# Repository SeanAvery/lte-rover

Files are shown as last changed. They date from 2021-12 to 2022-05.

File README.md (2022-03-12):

The goal is to control rc car remotely over lte network and stream video back in real time.

Its like a videogame but irl.

Imagine shredding new york city streets in a 1/8 scale that goes 40+ mph. doordash people stop buying electric bikes do the deliveries w small rover.

### Overview

Camera is a comma.ai style andrioid phone with front/back image sensor. The MCU is a simple arduino nano that controls brushelss motor via BLX100 ESC and a steering servo.

### controls flow

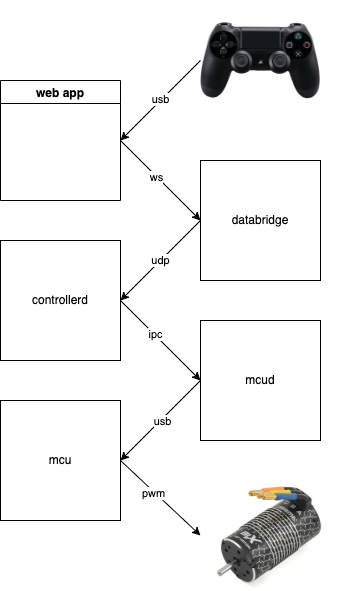
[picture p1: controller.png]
controls flow


### video flow

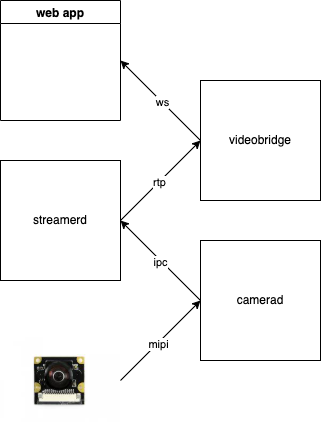
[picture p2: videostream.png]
videostream


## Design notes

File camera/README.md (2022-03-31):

# camera

This is basically turning into a mini-openpilot taking qualcomm camera code, usb communication stuff, and video encoding module out. Just need to add video streaming code (rtp or ideally webrtc/janus).

## Processes

### mcud

1. Libusb driver for mcu (ftdi)
2. Subscriber to `controls` events over zmq
3. Writes `controls` packets over usb
4. Reads `mcu_state` packets over usb

```
make build-mcud
./mcu

```

### controllerd
1. Daemon udp server receives packets from data-bridge
2. Publishes `controls` packets over zmq

```
make build-controllerd
./controller
```

### camerad

```
may just run straight op for this one

./camerad # from openpilot build
```

### streamerd
1. Accepts frame packets over VisionIPC
2. Encodes to h64 using OpenMax
3. Streams over RTP to video-bridge

```
make build-streamerd
./streamer
```

## Communication

### Wireless

Linux socket. Udp on wifi for now. 

Todo: tcp over lte

### Interprocess

checkout out openpilot's cereal library

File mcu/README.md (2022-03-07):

# mcu

Steering and throttle control from arduino.

The goal of this microntroller is to keep things simple - just receive serial commands, perform safety checks, and execute controls.

### hardware

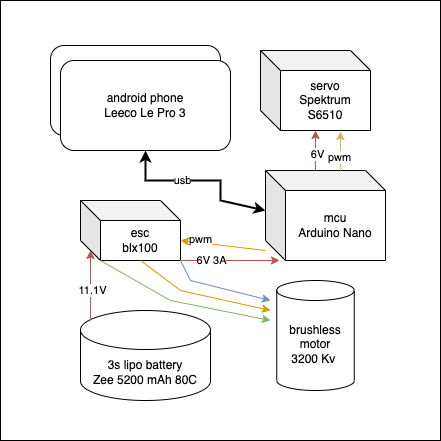
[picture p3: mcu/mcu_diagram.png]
mcu diagram


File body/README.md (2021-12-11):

All parts will be 3d printable (targeting ABS prints).

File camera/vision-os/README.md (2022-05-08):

Snapdragon 821 Vision Stack WIP

# why

openpilot codebase is good reference material but not well suited as robotics framework

plus 821 support has ended and the comma C3 dev board/cameras are way too expensive if you want to develop your own product

lets split software up into composable tools, and make a cheap/usable qualcomm dev board

# hardware setup

Leeco Le Pro 3 running NEOS

# mvp software

1. camera capture
2. encoder
3. rtp streamer

# reach goals

1. cython bindings
2. replacable camera/lens (imx 219 fisheye)

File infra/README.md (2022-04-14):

# infra

this is the cloud bridge for webrtc video streaming and controls

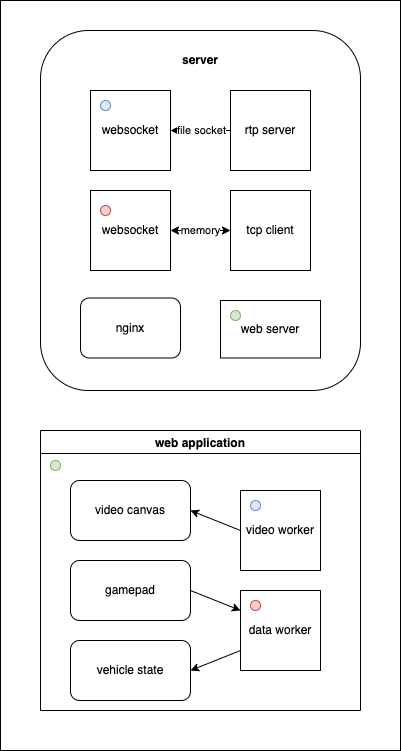
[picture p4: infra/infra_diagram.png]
infra architecture


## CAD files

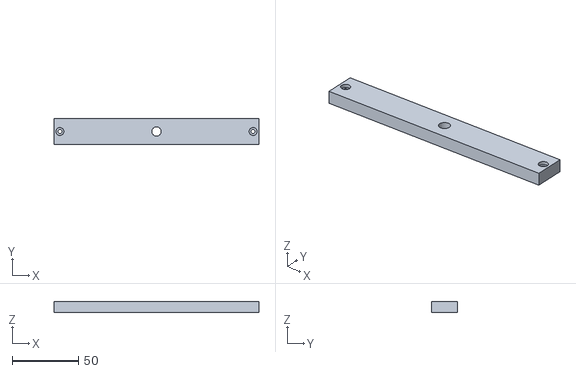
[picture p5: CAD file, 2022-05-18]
body/crossbeam.stl
155.0 x 20.0 x 8.00

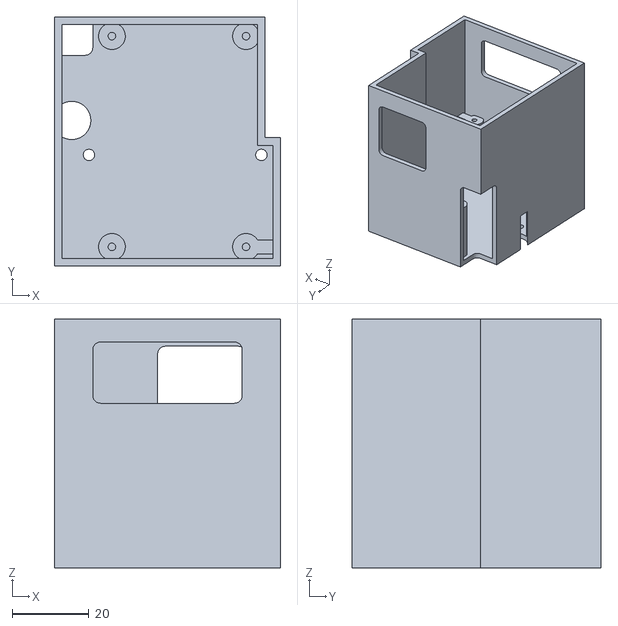
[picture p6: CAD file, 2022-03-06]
body/mcu_enclosure.stl
59.0 x 65.0 x 65.0

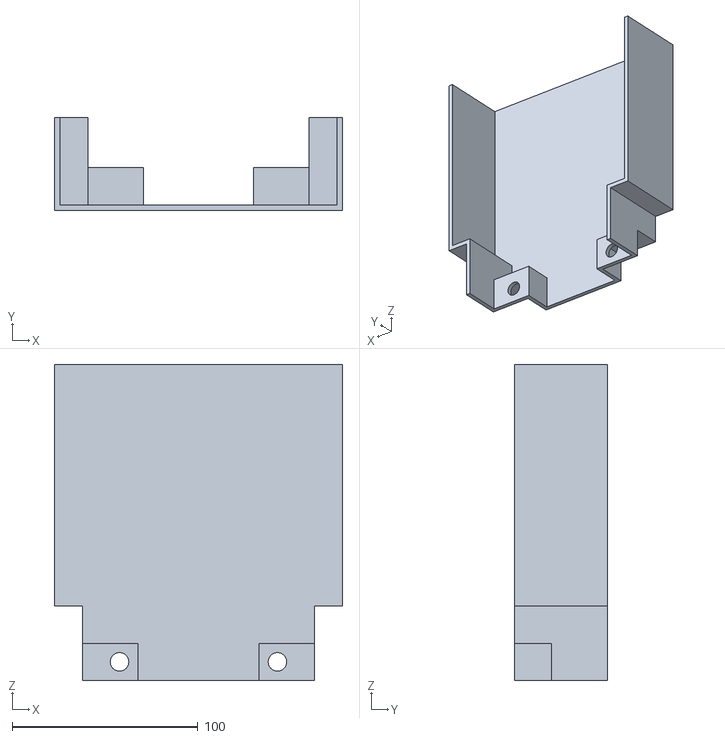
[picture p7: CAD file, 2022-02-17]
body/hood.stl
155.0 x 50.0 x 170.0

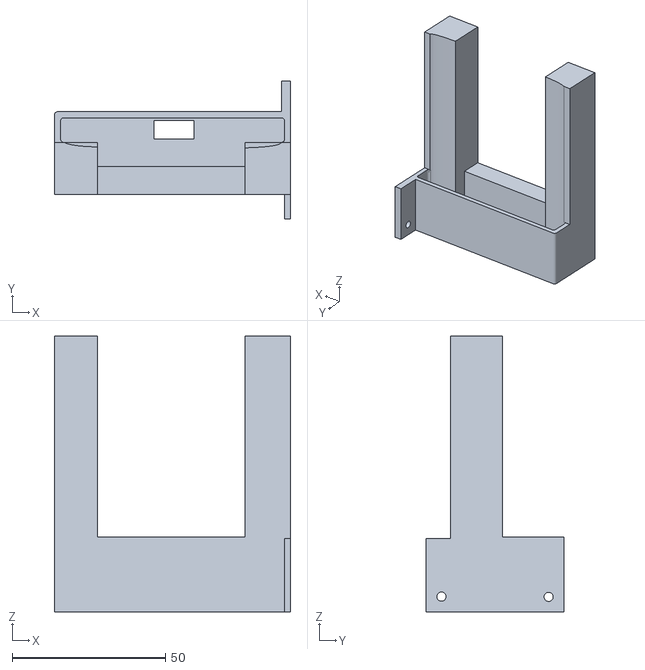
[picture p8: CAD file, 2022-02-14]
body/camera_mount_left.stl
77.0 x 45.0 x 90.0

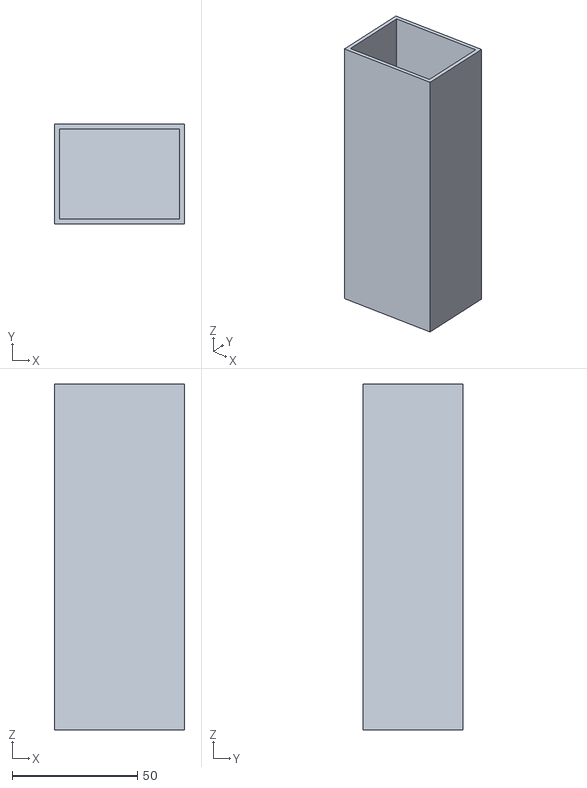
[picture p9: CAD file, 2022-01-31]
body/battery_case.stl
52.0 x 40.0 x 138.0

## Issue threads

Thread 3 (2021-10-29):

rear camera bringup

SeanAvery, 2021-10-29:
### Resources:

[v4l2 subdevices](https://01.org/linuxgraphics/gfx-docs/drm/media/kapi/v4l2-subdev.html)

[qualcomm camera subsystems](https://www.kernel.org/doc/html/v4.14/media/v4l-drivers/qcom_camss.html)

SeanAvery, 2021-10-30:
### Goal:

Need to reverse engineer the rear camera api on my one plus 3 device.

Hopefully, I can just copy the old openpilot camera code

SeanAvery, 2021-10-30:
### Qualcomm camera systems

`csiphy`: handles camera input

`csid`:

`ispif`:

`vfe`:

SeanAvery, 2021-11-10:
https://medium.com/@athul929/capture-an-image-using-v4l2-api-5b6022d79e1d

SeanAvery, 2021-11-18:
# csid cfg error

___

- [ ] try to match clang sdk version
- [ ] use clang that comes with openpilot
- [ ] check import structure
- [ ] debug the ioctl call

SeanAvery, 2021-11-19:
# camera specs (OV8865)

https://android.googlesource.com/kernel/msm.git/+/android-msm-bullhead-3.10-n-preview-1/drivers/media/platform/msm/camera_v2/Kconfig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

SeanAvery, 2021-11-19:
# [qualcomm msm kernel headers](https://android.googlesource.com/platform/hardware/qcom/msm8960/+/e1c9fe3f8195d664a60a04083c3f5de2402b8dee/original-kernel-headers/media)

SeanAvery, 2021-11-21:
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

SeanAvery, 2021-11-21:
###  [ov8865 driver](https://android.googlesource.com/kernel/msm/+/android-msm-shamu-3.10-m-preview/drivers/media/platform/msm/camera_v2/sensor/ov8865.c)

SeanAvery, 2021-11-22:
### [enable kernel debugging](https://elinux.org/Jetson/l4t/Camera_BringUp)

SeanAvery, 2021-11-22:
### [v4l2 events][(](https://www.kernel.org/doc/html/v4.9/media/kapi/v4l2-event.html))

Closed 2021-11-22.

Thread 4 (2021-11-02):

libusb communication bridge between camera and mcu

SeanAvery, 2021-11-02:
[libusb documentaion](https://libusb.sourceforge.io/api-1.0/)

SeanAvery, 2021-12-13:
- [x] get libusb linked to executable
- [x] find usb device
- [ ] up usb device
- [ ] send message
- [ ] receive message

SeanAvery, 2021-12-15:
[openpilot panda.cc](https://github.com/commaai/openpilot/blob/master/selfdrive/boardd/panda.cc)

SeanAvery, 2021-12-15:
[sync libusb tutorial](https://www.dreamincode.net/forums/topic/148707-introduction-to-using-libusb-10/)

SeanAvery, 2021-12-15:
[pigeon.cc]((https://github.com/commaai/openpilot/blob/master/selfdrive/boardd/pigeon.cc)

SeanAvery, 2022-01-20:
### usb ERRNOT
[stack overflow post](https://stackoverflow.com/questions/44122912/libusb-error-submit-bulk-transfer-submiturb-failed-error-1-errno-2-what-am)

SeanAvery, 2022-03-07:
- [ ] format message # protocol
- [ ] async write
- [ ] async read

SeanAvery, 2022-03-08:
### [libusb async tutorial](https://libusb.sourceforge.io/api-1.0/libusb_io.html)

Closed 2022-03-10.

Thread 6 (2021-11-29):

leeco le pro 3 camera specs

SeanAvery, 2021-11-29:

SeanAvery, 2021-12-01:
### [leeco specs](https://www.gsmarena.com/leeco_le_pro3-8344.php)

SeanAvery, 2022-04-22:
### rear camera

Sony IMX298 image sensor with autofocus lens
```
16 MP
f 2.0
```

### front camera

OV8865 sensor (autofocus ???)

```
8 MP
```

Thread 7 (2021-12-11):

arrma car harness

SeanAvery, 2021-12-11:
Control esc, steering servo, and motor fan from arduino

SeanAvery, 2021-12-11:
### debug esc pwm

SeanAvery, 2021-12-11:
### blx 100 esc
[
](https://www.arrma-rc.com/power-systems/latest/blx100)

SeanAvery, 2021-12-13:
should i add head/break lights : 0

SeanAvery, 2022-01-18:
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

SeanAvery, 2022-03-03:
use pins 5 and 6 on arduino nano for 980 Hz pwm

SeanAvery, 2022-03-05:
### problem: pwm dropoff when using usb interface

try things:

- [ ] cut power trace in usb cable from camera to mcu

SeanAvery, 2022-03-05:
### steering

[Spektrum S6510](https://www.hobbytown.com/spektrum-rc-s651-7kg-metal-gear-waterproof-servo-spms651/p1252957)

SeanAvery, 2022-03-06:
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

SeanAvery, 2022-03-07:
mcu 0.1 finished

Closed 2022-03-07.

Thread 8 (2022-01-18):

smart battery

SeanAvery, 2022-01-18:

SeanAvery, 2022-03-18:
[video tutorial](https://www.youtube.com/watch?v=gCS-p8VnSlg)

SeanAvery, 2022-03-26:
- [x] measure cells with multimeter

```
on full charge
cell 1:  10.41
cell 2: 6.23
cell 3: 3.12
```

SeanAvery, 2022-03-26:
- [ ] get current measurements
- [ ] calculate resistor scaling needed for arduino pins

AlexandreSato, 2022-04-13:
if u use same resistors so adc pin aways vin/2

SeanAvery, 2022-04-13:
@AlexandreSato Thanks for comment.

Yes tested using equal value resistors to drop voltage in half. Cell 3 is 11+V so need to drop more than that. Trying to figure out if I need separate arduino for battery or if I can fit it all in the mcu. If separated would need to communicate through usb hub and eon to the mcu or directly through the rx/tx lines.

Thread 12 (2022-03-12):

mcud: usb up issue

SeanAvery, 2022-03-12:
- [x] check if kernel is attached
- [x] check interface claim

SeanAvery, 2022-03-26:
works when i connect with python serial library then run custom libusb.

may be do to baudrate issue (check this later)

SeanAvery, 2022-03-29:
### [ftdi usb driver](https://github.com/wjakob/libftdi)

SeanAvery, 2022-03-31:
## libftdi
### pros:
Clean comprehensive library. Easy to build on device wtith clang and neos libusb pkg.

### cons:
Does not specifically support `FT232RL`. Reset and setting baudrate failing out of the box.

SeanAvery, 2022-03-31:
[FT232RL api docs](http://ibm-1401.info/FeretichEmulator/FT232_FT245_APIv131.pdf)

SeanAvery, 2022-03-31:
i got scammed! arduino nano knockoff does not actually ship with ftdi chip. it comes with `CH340`
https://cdn.sparkfun.com/datasheets/Dev/Arduino/Other/CH340DS1.PDF

SeanAvery, 2022-03-31:
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

SeanAvery, 2022-03-31:
## CH340G Driver

[nice libusb gist ](https://gist.github.com/z4yx/8d9ecad151dad351fbbb)

SeanAvery, 2022-04-01:
[Si lbas documentation](https://www.silabs.com/documents/public/application-notes/AN571.pdf)

SeanAvery, 2022-04-01:
### COM Driver Option

One option is to use the `CH341SER` driver to get COM port. And then just use serial library in python from there.

SeanAvery, 2022-04-01:
# wireshark usb snoop of ch340 arduino driver

[instructions](https://wiki.wireshark.org/CaptureSetup/USB)

SeanAvery, 2022-04-01:
ch340g driver working

Closed 2022-04-01.

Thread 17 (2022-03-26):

mcu: usb bulk write timeout bug

SeanAvery, 2022-03-26:
### problem:
 I cannot bulk read or write faster than 1 hz!

SeanAvery, 2022-04-01:
[CRC communication](https://www.usb.org/sites/default/files/crcdes.pdf)

SeanAvery, 2022-04-05:
### update

1. bulk reads are working at fast hz
2. bulk writes only working at 1 hz

SeanAvery, 2022-04-05:
make sure packet size is correct!

Closed 2022-04-05.

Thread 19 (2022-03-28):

macos/sony dualshock controls

SeanAvery, 2022-03-28:
- [x] controller bringup
- [x] serial bringup
- [x] gamepad poll
- [x] parse gamepad state
- [x] send controls to mcu

SeanAvery, 2022-03-28:
### Problem:  pygame is unmaintained, joystick stuff doesnt work...

### Solution: use raw [hid](https://blog.thea.codes/talking-to-gamepads-without-pygame/) outputs

SeanAvery, 2022-03-28:
```
'vendor_id': 1356, 'product_id': 2508
```

SeanAvery, 2022-03-28:
normalize analog joystick to steering range

```
>>> (2 * ((value - 0) / (256 - 0))) - 1
```

Closed 2022-03-28.

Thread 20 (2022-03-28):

mcu: msg parsing causes jitter

SeanAvery, 2022-03-28:
### Problem:

msg parsing occasionally parses erroneous values from the serial stream. This causes steering and throttle to jitter and jerk.

SeanAvery, 2022-03-29:
This issue is fixed on the client side by polling read. (Flushes out inputs). Will revisit later if problem reappears.

Closed 2022-03-29.

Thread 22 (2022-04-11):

blx100 arm forward/break/reverse correctly

SeanAvery, 2022-04-11:
```
Reverse: 86 - 20
Forward: 94-160
Breaking: ???
```

SeanAvery, 2022-04-12:
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

Closed 2022-04-13.

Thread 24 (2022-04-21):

wide video feed (op camerad)

SeanAvery, 2022-04-21:

SeanAvery, 2022-04-22:
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

SeanAvery, 2022-04-22:
width: 1164
height: 874

SeanAvery, 2022-04-23:
[video_writer.cc](https://github.com/commaai/openpilot/commit/8d2465578707022ca4a54defe171103955026a65)

SeanAvery, 2022-05-06:
### Problem

`VisionIPC` client returns raw output from debayer step in camerad. This is not formatted properly and requires expensive transform. Too slow for numpy transform in video pipeline.

Closed 2022-05-08.

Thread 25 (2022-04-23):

cellular interface up without comma prime

SeanAvery, 2022-04-23:

SeanAvery, 2022-04-23:
[android network stack](https://source.android.com/devices/architecture/hidl/network-stack)

SeanAvery, 2022-04-23:
looks like the commercial lte interface is up and running

```
rmnet_data7 Link encap:UNSPEC  HWaddr 00-00-00-00-00-00-00-00-00-00-00-00-00-00-00-00
          UP RUNNING  MTU:2000  Metric:1
          RX packets:9 errors:0 dropped:0 overruns:0 frame:0
          TX packets:12 errors:0 dropped:0 overruns:0 carrier:0
          collisions:0 txqueuelen:1000
          RX bytes:669 (669.0 B)  TX bytes:881 (881.0 B)
```

may be able to assign ip and use data. lets go!

SeanAvery, 2022-04-23:
[RMNet](https://www.kernel.org/doc/html/latest/networking/device_drivers/cellular/qualcomm/rmnet.html)

SeanAvery, 2022-04-26:
comma prime lite ssh proxy does not work with third party sim.

SeanAvery, 2022-04-26:
modem path:
`/sys/devices/soc/2080000.qcom,mss/subsys5`

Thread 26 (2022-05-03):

fix loose camera female thread on crossbeam

SeanAvery, 2022-05-03:

Closed 2022-05-05.

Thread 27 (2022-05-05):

fisheye camera replacement research

SeanAvery, 2022-05-05:
Swap out camera sensor and lens

[sony imx219](https://www.seeedstudio.com/IMX219-160-Camera-160-FOV-Applicable-for-Raspberry-Pi-V2-Camera-p-4604.html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)

SeanAvery, 2022-05-11:
### [example sonyimx219 linux driver](https://elixir.bootlin.com/linux/latest/source/drivers/media/i2c/imx219.c)

SeanAvery, 2022-05-11:
### [example sony imx323 android kernel driver](https://github.com/TinkerBoard/android-6.0.1_kernel/blob/develop/drivers/media/i2c/soc_camera/rockchip/imx323_v4l2-i2c-subdev.c)

SeanAvery, 2022-05-14:
### [camera v2 kernel](https://github.com/commaai/android_kernel_leeco_msm8996/tree/master/drivers/media/platform/msm/camera_v2)

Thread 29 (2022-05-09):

camera capture from scratch

SeanAvery, 2022-05-09:

SeanAvery, 2022-05-14:
https://linux-media.vger.kernel.narkive.com/i8K77VkT/rfc-v4l2-driver-for-qualcomm-msm-camera

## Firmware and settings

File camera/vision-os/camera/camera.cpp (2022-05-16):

#include <iostream>

#include "linux/videodev2.h"
#include "unistd.h"
#include "assert.h"

#include "camera.h"
#include "common.h"

// TOOLS

int sensor_write_regs(CameraState *s, struct msm_camera_i2c_reg_array *arr, size_t size, msm_camera_i2c_data_type data_type) {
  int err = 0;
  struct msm_camera_i2c_reg_setting out_settings = {
    .reg_setting = arr,
    .size = (uint16_t)size,
    .addr_type = MSM_CAMERA_I2C_WORD_ADDR,
    .data_type = data_type,
    .delay = 0,
  };
  sensorb_cfg_data cfg_data = {.cfgtype = CFG_WRITE_I2C_ARRAY, .cfg.setting = &out_settings };
  std::cout << "sensor_fd: " << s->subdevices.sensor_fd << std::endl;
  err = cam_ioctl(s->subdevices.sensor_fd, VIDIOC_MSM_SENSOR_CFG, &cfg_data, "init camera");
  return err;
}

// CONTROL

// init

static int camera_init() {
  int err = 0;
  return err;
}

// open

static int camera_shutdown(struct CameraState *camera) {
  int err = 0;

  struct msm_camera_csi_lane_params csi_lane_params = { 0 };
  csi_lane_params.csi_lane_mask = 0x1f;
  csiphy_cfg_data csiphy_cfg = { .cfg.csi_lane_params = &csi_lane_params, .cfgtype = CSIPHY_RELEASE };
  err = cam_ioctl(camera->subdevices.csiphy_fd, VIDIOC_MSM_CSIPHY_IO_CFG, &csiphy_cfg, "release csiphy");

  struct csid_cfg_data csid_cfg = { .cfgtype = CSID_RELEASE };
  err = cam_ioctl(camera->subdevices.csid_fd, VIDIOC_MSM_CSID_IO_CFG, &csid_cfg, "release csid");

  struct sensorb_cfg_data sensorb_cfg = { .cfgtype = CFG_POWER_DOWN };
  err = cam_ioctl(camera->subdevices.sensor_fd, VIDIOC_MSM_SENSOR_CFG, &sensorb_cfg, "sensor power down");

  return err;
}

static int camera_up(struct CameraState *camera) {
  int err = 0;

  struct csid_cfg_data csid_cfg = { .cfgtype = CSID_INIT };
  err = cam_ioctl(camera->subdevices.csid_fd, VIDIOC_MSM_CSID_IO_CFG, &csid_cfg, "init csid");

  struct csiphy_cfg_data csiphy_cfg = { .cfgtype = CSIPHY_INIT };
  err = cam_ioctl(camera->subdevices.csiphy_fd, VIDIOC_MSM_CSIPHY_IO_CFG, &csiphy_cfg, "init csiphy");

  struct sensorb_cfg_data sensorb_cfg = { .cfgtype = CFG_POWER_UP };
  err = cam_ioctl(camera->subdevices.sensor_fd, VIDIOC_MSM_SENSOR_CFG, &sensorb_cfg, "sensor power up");

  err = sensor_write_regs(camera, init_array_imx298, std::size(init_array_imx298), MSM_CAMERA_I2C_BYTE_DATA);

  err = sensor_write_regs(camera, mode_setting_array_imx298, std::size(mode_setting_array_imx298), MSM_CAMERA_I2C_BYTE_DATA);

  csid_params.lut_params.vc_cfg[0] = &csid_params.lut_params.vc_cfg_a[0];
  csid_params.lut_params.vc_cfg[1] = &csid_params.lut_params.vc_cfg_a[1];
  csid_params.lut_params.vc_cfg[2] = &csid_params.lut_params.vc_cfg_a[2];
  csid_cfg.cfgtype = CSID_CFG;
  csid_cfg.cfg.csid_params = &csid_params;
  cam_ioctl(camera->subdevices.csid_fd, VIDIOC_MSM_CSID_IO_CFG, &csid_cfg, "csid configure");

  return err;
}

static int camera_configure_stream(struct CameraState *camera) {
  int err = 0;
  msm_vfe_smmu_attach_cmd smmu_cmd = { .security_mode = 0, .iommu_attach_mode = IOMMU_ATTACH };
  err = cam_ioctl(camera->subdevices.isp_fd, VIDIOC_MSM_ISP_SMMU_ATTACH, &smmu_cmd, "isp smmu attach");
  return err;
}

static void sensors_init(struct CameraState *camera) {
  cam_info.power_setting_array.power_setting = &cam_info.power_setting_array.power_setting_a[0];
  cam_info.power_setting_array.power_down_setting = &cam_info.power_setting_array.power_down_setting_a[0];
  sensor_init_cfg_data sensor_init_cfg = {.cfgtype = CFG_SINIT_PROBE, .cfg.setting = &cam_info};
  int err = cam_ioctl(camera->subdevices.sensor_init_fd, VIDIOC_MSM_SENSOR_INIT_CFG, &sensor_init_cfg, "sensor init cfg");
  // allow time for sensor to init
  for (int i = 0; i < 10; i++) {
    camera->subdevices.sensor_fd = open("/dev/v4l-subdev17", O_RDWR | O_NONBLOCK);
    if (camera->subdevices.sensor_fd > 0) break;
    std::cout << "waiting for sensor susbsytem init" << std::endl;
    usleep(1000000); // sleep for 1 second
  }
}

static int camera_open(struct CameraState *camera) {
  int err = 0;

  // connect to v4l subsystem files (IMX298)
  camera->subdevices.ispif_fd = open("/dev/v4l-subdev15", O_RDWR | O_NONBLOCK);

  camera->subdevices.sensor_init_fd = open("/dev/v4l-subdev11", O_RDWR | O_NONBLOCK);
  assert(camera->subdevices.sensor_init_fd > 0);
  camera->subdevices.csid_fd = open("/dev/v4l-subdev3", O_RDWR | O_NONBLOCK);
  assert(camera->subdevices.csid_fd > 0);
  camera->subdevices.csiphy_fd = open("/dev/v4l-subdev0", O_RDWR | O_NONBLOCK);
  assert(camera->subdevices.csiphy_fd > 0);
  camera->subdevices.isp_fd = open("/dev/v4l-subdev13", O_RDWR | O_NONBLOCK);
  assert(camera->subdevices.isp_fd > 0);

  sensors_init(camera);

  assert(camera->subdevices.sensor_fd > 0);

  camera_shutdown(camera);
  camera_up(camera);
  camera_configure_stream(camera);

  return err;
}

// start

static int camera_start(struct CameraState *camera) {
  int err = 0;
  err = sensor_write_regs(camera, start_reg_array, std::size(start_reg_array), MSM_CAMERA_I2C_BYTE_DATA);
  return err;
}

// TEST

int main() {
  int err = 0;
  std::cout << "starting camera capture" << std::endl;
  CameraState camera = {};
  // init
  // open
  err = camera_open(&camera);
  // err = camera_start(&camera);
}

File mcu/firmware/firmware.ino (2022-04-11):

#include <stdlib.h>

#include <Servo.h>
#include <SoftwareSerial.h>

// servo instances
Servo steeringServo;
Servo motorEsc;

// global variables
int angle = 90;
int throttle = 90;
int minAngle = 70;
int maxAngle = 110;
int centerAngle = 90; 
int minThrottleForward = 90;
int maxThrottleFortward = 160;
int minThrottleaReverse = 90;
int maxThrottleReverse = 20;

char throttleIndex = 't';
char steeringIndex = 's';
char escapeIndex = '#';

void setup() {
  // setup serial communication over usb port
  Serial.begin(115200);
  // wait for serial port to connect
  while (!Serial) {
    ;
  }
  Serial.println("serial port is connected");
  // setup pwm pins for steering and motor control
  steeringServo.attach(6);
  motorEsc.attach(5);
}

bool steering_safe(int value)
{
  if (value > maxAngle) 
  {
    return false;
  }
  if (value < minAngle) 
  {
    return false;
  }
  return true;
}

bool throttle_safe(int value)
{
  if (value > maxThrottleFortward) 
  {
    return false;
  }
  if (value < maxThrottleReverse) 
  {
    return false;
  }
  return true;
}

void loop() {
  delay(1);
  if (Serial.available())
  {
    char serialMsg[7];
    size_t msgLength = Serial.readBytesUntil(escapeIndex, serialMsg, 20);

    if (msgLength == 6)
    {
      char header;
      int value;
      sscanf(serialMsg, "%c%5d", header, &value);

      if (serialMsg[0] == throttleIndex) {
        if (throttle_safe(value))
        {
          throttle = value;
        }
      }
      else if (serialMsg[0] == steeringIndex)
      {
        if (steering_safe(value))
        {
          angle = value;
        }
      }
    }
  }
  Serial.println("#"); // heartbeat
  motorEsc.write(throttle);
  steeringServo.write(angle);
}

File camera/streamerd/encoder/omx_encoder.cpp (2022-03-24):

#include "omx_encoder.h"

#define PORT_INDEX_IN 0
#define PORT_INDEX_OUT 1
#define BITRATE 5000000
#define FPS 20

// Check the OMX error code and assert if an error occurred.
#define OMX_CHECK(_expr)              \
  do {                                \
    assert(OMX_ErrorNone == (_expr)); \
  } while (0)

static const char* omx_color_fomat_name(uint32_t format) __attribute__((unused));
static const char* omx_color_fomat_name(uint32_t format) {
  switch (format) {
  case OMX_COLOR_FormatUnused: return "OMX_COLOR_FormatUnused";
  case OMX_COLOR_FormatMonochrome: return "OMX_COLOR_FormatMonochrome";
  case OMX_COLOR_Format8bitRGB332: return "OMX_COLOR_Format8bitRGB332";
  case OMX_COLOR_Format12bitRGB444: return "OMX_COLOR_Format12bitRGB444";
  case OMX_COLOR_Format16bitARGB4444: return "OMX_COLOR_Format16bitARGB4444";
  case OMX_COLOR_Format16bitARGB1555: return "OMX_COLOR_Format16bitARGB1555";
  case OMX_COLOR_Format16bitRGB565: return "OMX_COLOR_Format16bitRGB565";
  case OMX_COLOR_Format16bitBGR565: return "OMX_COLOR_Format16bitBGR565";
  case OMX_COLOR_Format18bitRGB666: return "OMX_COLOR_Format18bitRGB666";
  case OMX_COLOR_Format18bitARGB1665: return "OMX_COLOR_Format18bitARGB1665";
  case OMX_COLOR_Format19bitARGB1666: return "OMX_COLOR_Format19bitARGB1666";
  case OMX_COLOR_Format24bitRGB888: return "OMX_COLOR_Format24bitRGB888";
  case OMX_COLOR_Format24bitBGR888: return "OMX_COLOR_Format24bitBGR888";
  case OMX_COLOR_Format24bitARGB1887: return "OMX_COLOR_Format24bitARGB1887";
  case OMX_COLOR_Format25bitARGB1888: return "OMX_COLOR_Format25bitARGB1888";
  case OMX_COLOR_Format32bitBGRA8888: return "OMX_COLOR_Format32bitBGRA8888";
  case OMX_COLOR_Format32bitARGB8888: return "OMX_COLOR_Format32bitARGB8888";
  case OMX_COLOR_FormatYUV411Planar: return "OMX_COLOR_FormatYUV411Planar";
  case OMX_COLOR_FormatYUV411PackedPlanar: return "OMX_COLOR_FormatYUV411PackedPlanar";
  case OMX_COLOR_FormatYUV420Planar: return "OMX_COLOR_FormatYUV420Planar";
  case OMX_COLOR_FormatYUV420PackedPlanar: return "OMX_COLOR_FormatYUV420PackedPlanar";
  case OMX_COLOR_FormatYUV420SemiPlanar: return "OMX_COLOR_FormatYUV420SemiPlanar";
  case OMX_COLOR_FormatYUV422Planar: return "OMX_COLOR_FormatYUV422Planar";
  case OMX_COLOR_FormatYUV422PackedPlanar: return "OMX_COLOR_FormatYUV422PackedPlanar";
  case OMX_COLOR_FormatYUV422SemiPlanar: return "OMX_COLOR_FormatYUV422SemiPlanar";
  case OMX_COLOR_FormatYCbYCr: return "OMX_COLOR_FormatYCbYCr";
  case OMX_COLOR_FormatYCrYCb: return "OMX_COLOR_FormatYCrYCb";
  case OMX_COLOR_FormatCbYCrY: return "OMX_COLOR_FormatCbYCrY";
  case OMX_COLOR_FormatCrYCbY: return "OMX_COLOR_FormatCrYCbY";
  case OMX_COLOR_FormatYUV444Interleaved: return "OMX_COLOR_FormatYUV444Interleaved";
  case OMX_COLOR_FormatRawBayer8bit: return "OMX_COLOR_FormatRawBayer8bit";
  case OMX_COLOR_FormatRawBayer10bit: return "OMX_COLOR_FormatRawBayer10bit";
  case OMX_COLOR_FormatRawBayer8bitcompressed: return "OMX_COLOR_FormatRawBayer8bitcompressed";
  case OMX_COLOR_FormatL2: return "OMX_COLOR_FormatL2";
  case OMX_COLOR_FormatL4: return "OMX_COLOR_FormatL4";
  case OMX_COLOR_FormatL8: return "OMX_COLOR_FormatL8";
  case OMX_COLOR_FormatL16: return "OMX_COLOR_FormatL16";
  case OMX_COLOR_FormatL24: return "OMX_COLOR_FormatL24";
  case OMX_COLOR_FormatL32: return "OMX_COLOR_FormatL32";
  case OMX_COLOR_FormatYUV420PackedSemiPlanar: return "OMX_COLOR_FormatYUV420PackedSemiPlanar";
  case OMX_COLOR_FormatYUV422PackedSemiPlanar: return "OMX_COLOR_FormatYUV422PackedSemiPlanar";
  case OMX_COLOR_Format18BitBGR666: return "OMX_COLOR_Format18BitBGR666";
  case OMX_COLOR_Format24BitARGB6666: return "OMX_COLOR_Format24BitARGB6666";
  case OMX_COLOR_Format24BitABGR6666: return "OMX_COLOR_Format24BitABGR6666";

  case OMX_COLOR_FormatAndroidOpaque: return "OMX_COLOR_FormatAndroidOpaque";
  case OMX_TI_COLOR_FormatYUV420PackedSemiPlanar: return "OMX_TI_COLOR_FormatYUV420PackedSemiPlanar";
  case OMX_QCOM_COLOR_FormatYVU420SemiPlanar: return "OMX_QCOM_COLOR_FormatYVU420SemiPlanar";
  case OMX_QCOM_COLOR_FormatYUV420PackedSemiPlanar64x32Tile2m8ka: return "OMX_QCOM_COLOR_FormatYUV420PackedSemiPlanar64x32Tile2m8ka";
  case OMX_SEC_COLOR_FormatNV12Tiled: return "OMX_SEC_COLOR_FormatNV12Tiled";
  case OMX_QCOM_COLOR_FormatYUV420PackedSemiPlanar32m: return "OMX_QCOM_COLOR_FormatYUV420PackedSemiPlanar32m";

  // case QOMX_COLOR_FormatYVU420SemiPlanar: return "QOMX_COLOR_FormatYVU420SemiPlanar";
  case QOMX_COLOR_FormatYVU420PackedSemiPlanar32m4ka: return "QOMX_COLOR_FormatYVU420PackedSemiPlanar32m4ka";
  case QOMX_COLOR_FormatYUV420PackedSemiPlanar16m2ka: return "QOMX_COLOR_FormatYUV420PackedSemiPlanar16m2ka";
  // case QOMX_COLOR_FormatYUV420PackedSemiPlanar64x32Tile2m8ka: return "QOMX_COLOR_FormatYUV420PackedSemiPlanar64x32Tile2m8ka";
  // case QOMX_COLOR_FORMATYUV420PackedSemiPlanar32m: return "QOMX_COLOR_FORMATYUV420PackedSemiPlanar32m";
  case QOMX_COLOR_FORMATYUV420PackedSemiPlanar32mMultiView: return "QOMX_COLOR_FORMATYUV420PackedSemiPlanar32mMultiView";
  case QOMX_COLOR_FORMATYUV420PackedSemiPlanar32mCompressed: return "QOMX_COLOR_FORMATYUV420PackedSemiPlanar32mCompressed";
  case QOMX_COLOR_Format32bitRGBA8888: return "QOMX_COLOR_Format32bitRGBA8888";
  case QOMX_COLOR_Format32bitRGBA8888Compressed: return "QOMX_COLOR_Format32bitRGBA8888Compressed";

  default:
    return "unkn";
  }
}

// OMX callbakcs

void OmxEncoder::wait_for_state(OMX_STATETYPE state) {
  std::unique_lock lk(this->state_lock);
  while (this->state != state) {
    this->state_cv.wait(lk);
  }
};

OMX_ERRORTYPE OmxEncoder::event_handler(OMX_HANDLETYPE component, OMX_PTR app_data, OMX_EVENTTYPE event,
                                   OMX_U32 data1, OMX_U32 data2, OMX_PTR event_data) {
  OmxEncoder *e = (OmxEncoder*)app_data;
  if (event == OMX_EventCmdComplete) {
    assert(data1 == OMX_CommandStateSet);
    // LOG("set state event 0x%x", data2);
    {
      std::unique_lock lk(e->state_lock);
      e->state = (OMX_STATETYPE)data2;
    }
    e->state_cv.notify_all();
  } else if (event == OMX_EventError) {
    // LOGE("OMX error 0x%08x", data1);
  } else {
    // LOGE("OMX unhandled event %d", event);
    assert(false);
  }

  return OMX_ErrorNone;
}

OMX_ERRORTYPE OmxEncoder::empty_buffer_done(OMX_HANDLETYPE component, OMX_PTR app_data,
                                                   OMX_BUFFERHEADERTYPE *buffer) {
  OmxEncoder *e = (OmxEncoder*)app_data;
  e->free_in.push(buffer);
  return OMX_ErrorNone;
}

OMX_ERRORTYPE OmxEncoder::fill_buffer_done(OMX_HANDLETYPE component, OMX_PTR app_data,
                                                  OMX_BUFFERHEADERTYPE *buffer) {
  OmxEncoder *e = (OmxEncoder*)app_data;
  e->done_out.push(buffer);
  return OMX_ErrorNone;
}

static OMX_CALLBACKTYPE omx_callbacks = {
  .EventHandler = OmxEncoder::event_handler,
  .EmptyBufferDone = OmxEncoder::empty_buffer_done,
  .FillBufferDone = OmxEncoder::fill_buffer_done,
};
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

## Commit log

2021-10-21 steering/motor ctrl
2021-10-30 add steering/throttle msging
2021-10-30 start camera mod
2021-10-31 android qualcomm camera kernel header files.
2021-11-01 powerdown ioctl calls
2021-11-01 camera sensor loop
2021-11-08 fix steering and throttle msgs
    [mcu.ino]
2021-11-08 adding safety checks on throttle/steering
2021-11-08 keyboard controller for throttle steering
2021-11-08 thread for camerad
2021-11-10 i2c config
2021-11-17 add i2c write method
2021-11-17 sensor powerup
2021-11-18 these driver calls actually working??
2021-11-19 openpilot props
2021-11-21 fix button press
2021-11-22 add std::thread
2021-12-01 sony imx298 sensor init
2021-12-11 ugly hood
    [hood.stl]
2021-12-11 newb shit
    [mcu_enclosure.stl]
2021-12-11 need usb hole
    [mcu_enclosure.stl]
2021-12-11 Add room for brushless cables
    [mcu_enclosure.stl]
2021-12-12 starting switch away from macos build system
2021-12-12 screw holes
    [mcu_enclosure.stl]
2021-12-12 start of phone mount
    [camera_mount_left.stl]
2021-12-13 which devices
2021-12-13 why my 3d models suck
    [camera_mount_left.stl]
2021-12-13 steering/throttle cal for blx100
2021-12-13 new calibration
2021-12-14 add screw mounts
    [camera_mount_left.stl]
2022-01-18 new new
    [mcu_enclusure.stl]
2022-01-18 mcu mount fits
    [mcu_enclosure.stl]
2022-01-20 steering test loop
2022-01-31 small updates to mcu enclosure
    [mcu_enclosure.stl]
2022-01-31 init battery case
    [battery_case.stl]
2022-02-14 cam mount fixes
    [camera_mount_left.stl]
2022-02-14 new hood
    [hood.stl]
2022-02-17 simple hood
    [hood.stl]
2022-02-17 sizing fixes for mcu mount
    [mcu_enclosure.stl]
2022-02-17 simple mount
    [crossbeam.stl]
2022-02-18 steering test
2022-02-18 test steering
2022-02-19 sample rtp config
2022-03-04 reduce steering range
2022-03-05 slight adjustments to crossbeam
    [crossbeam.stl]
2022-03-06 add more space in trunk for screws
    [mcu_enclosure.stl]
2022-03-06 fix wall thickness
    [mcu_enclosure.stl]
2022-03-06 small fxs
    [mcu_enclosure.stl]
2022-03-07 wiring diagram
2022-03-08 init socket
2022-03-09 socket workin
2022-03-13 creating sub socket
2022-03-13 pub socket
2022-03-13 message chain
2022-03-13 steering calc based on left joystick
2022-03-14 run builds on device
2022-03-17 start process thread
2022-03-18 camera sub
2022-03-21 start encoder
2022-03-24 encoder open stub
2022-03-24 helper script for cameradf startup
2022-03-28 steering with joystick working
2022-03-28 add throttle up down left joystick
2022-03-31 starting ch340g driver
2022-04-01 ch340g driver in works
2022-04-01 driver working lets go
2022-04-11 run mcud at 100 hz
2022-04-11 handle throttle in web app
2022-04-12 right joystick throttle much better
2022-04-14 init node video relay
2022-05-05 update crossbeam
    [crossbeam.stl]
2022-05-09 start camera capture again
2022-05-10 camera shutdown
2022-05-10 init sensor
2022-05-10 smmu attach
2022-05-16 camera sensor init
2022-05-18 small fix to crossbeam
    [crossbeam.stl]
